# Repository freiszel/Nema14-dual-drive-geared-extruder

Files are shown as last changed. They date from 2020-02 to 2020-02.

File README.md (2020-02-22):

# Nema14-dual-drive-geared-extruder
A Nema 14 dual drive geared extruder made from scratch. The prject was made with SolidWoks 2010 
(any posterior version of SolidWorks will open the files). The SolidWors2010 folder contains all the parts required,
as weel as the assembly file "Gear 15x69.SLDASM". 15x69 stands for the gears' teeth number used in the project.  

The project was used to extrude a 1.75 mm ABS filament heated to 220C through a 0,4 mm nozzle. A Feed Rate of 9 mm/s
was possible without slipping or motor stall. ths means that flow rate obtained was 25 mm3/s, enough to print at 
speeds of 200 mm/s.

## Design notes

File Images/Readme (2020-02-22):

Images show the mounting sequence of all parts of the Nema14 Dual Drive Geared Extruder.

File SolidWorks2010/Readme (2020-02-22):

Solidworks2010 files of all parts of the Nema14 Dual Drive Geared Extruder.
The Assembly file is  "Gear 15x69.SLDASM".
15x69 stands for the gears' teeth number.

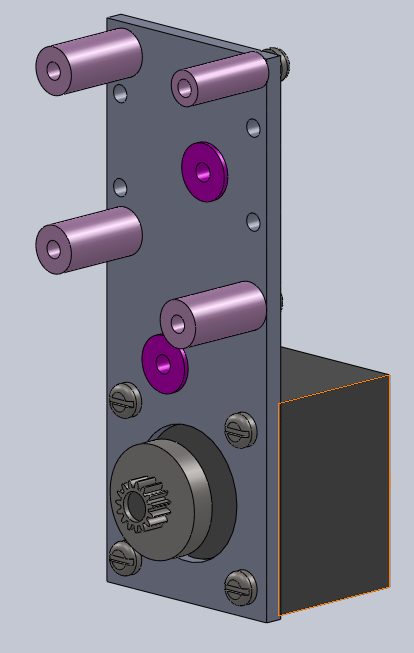
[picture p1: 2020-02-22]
Images/02_BackPlateMounted.png

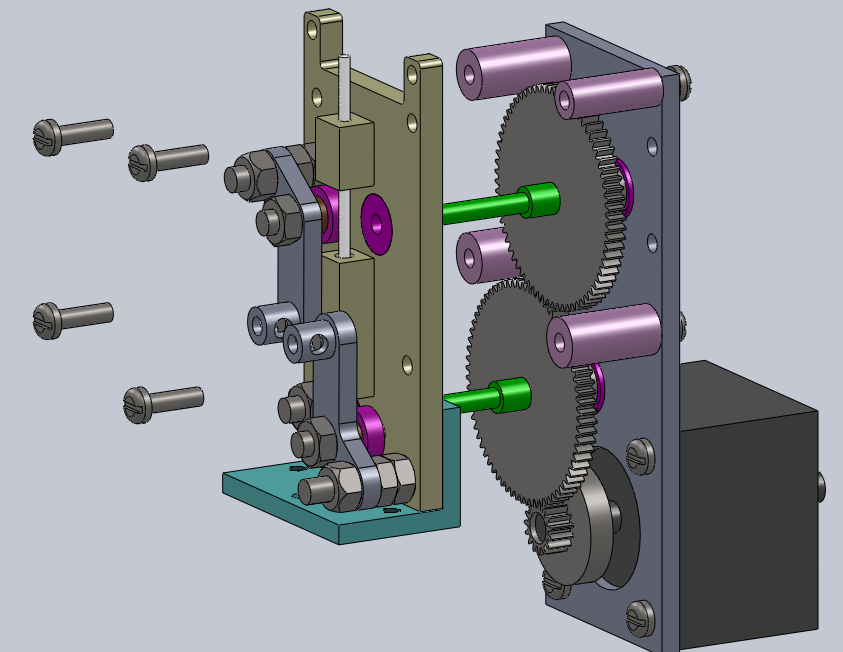
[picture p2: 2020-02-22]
Images/10_FrontToRealMounting.png

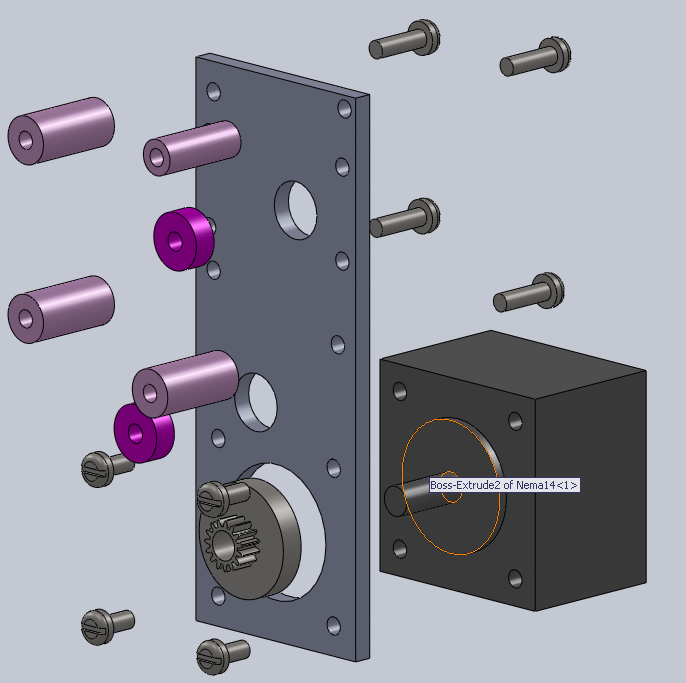
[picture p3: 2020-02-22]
Images/01_BackPlateMounting.png

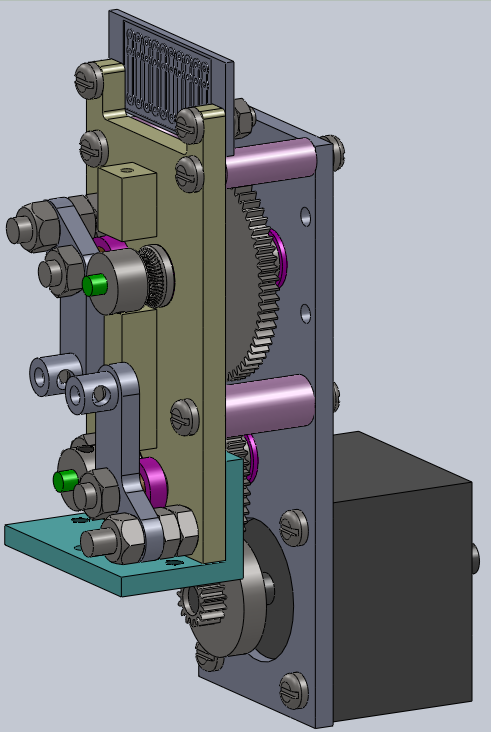
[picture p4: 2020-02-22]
Images/13_DriversAndConectorFixed.png

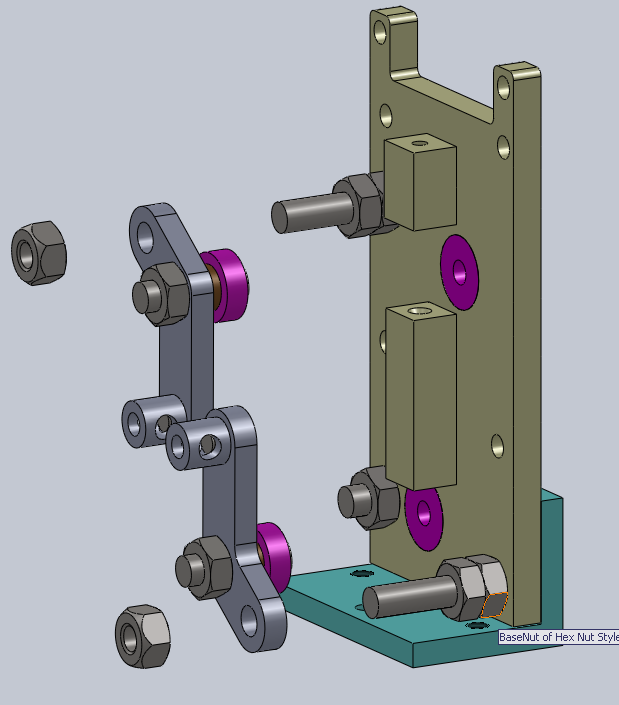
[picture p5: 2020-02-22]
Images/08_AttachPressingArms.png

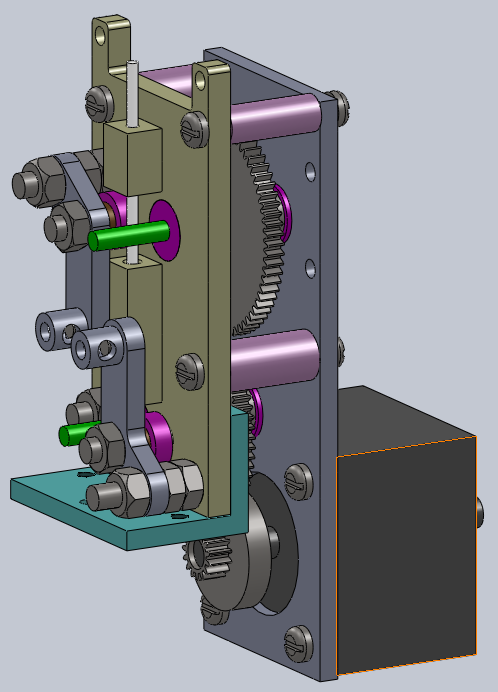
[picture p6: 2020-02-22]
Images/11_FrontToRearMounted.png

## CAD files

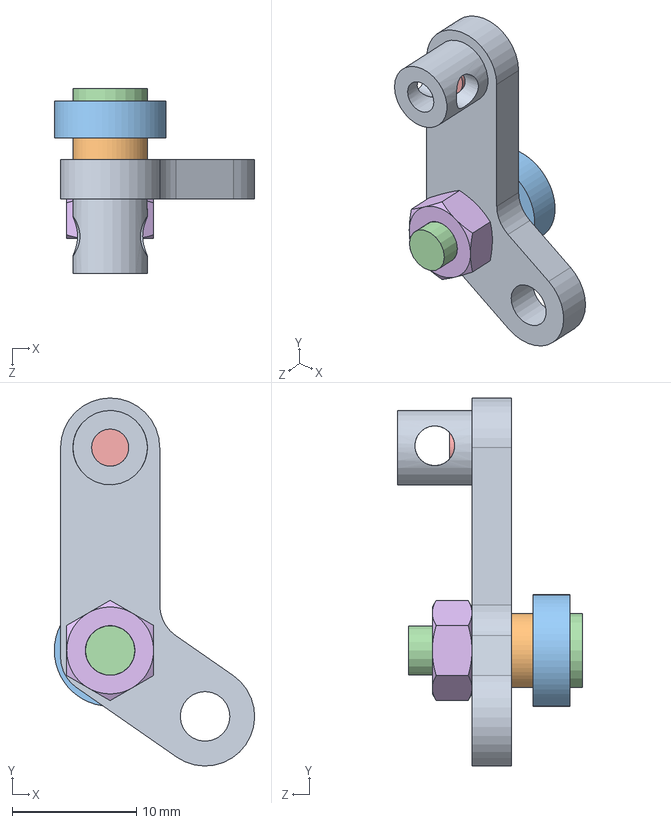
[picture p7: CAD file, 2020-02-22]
SolidWorks2010/PressingArm.SLDASM
16.1 x 29.7 x 14.9 mm
alavanca
BrassBush
bear 9 x 5 x 3mm
FlatScrew
Flat Head Screw_AM
Hex Nut Style 1_AM

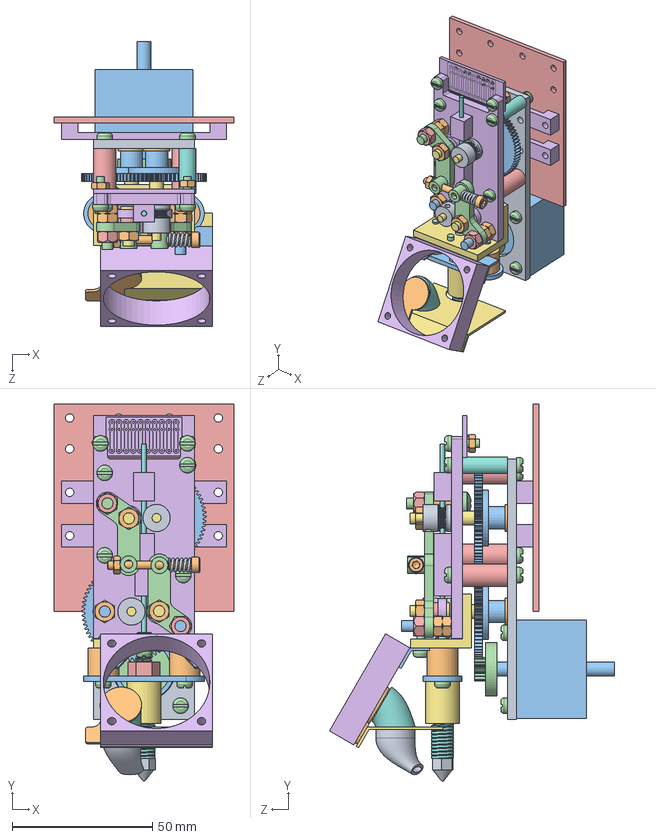
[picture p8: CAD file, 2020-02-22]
SolidWorks2010/Gear 15x69.SLDASM
64.0 x 134.4 x 101.7 mm
rear
bear 3 16 x x1 8 x 4mm x 4
Nema14
GearN15M05
fixacaoX
front
aba
filamento
trator x 2
Hex Nut Style 1_AM x 10
Flat Head Screw_AM x 4
Pan Cross Head_AM
Prevailing Torque Hex Nut_am x 2
Ponte x 2
Peek
heater
nozzle
PeekPilar x 2
fibra
Teflon
PeekNut
fan
coifa1
coifa2
coifa3
bloqueador
CollerFix
Pan Slot Head_AM x 17
Pilar x 3
conector
Pino x 2
Pilar 6mm
spring
Socket Head Cap Screw_AM
GearN69M05 x 2
alavanca x 2
BrassBush x 2
bear 9 x 5 x 3mm x 2
FlatScrew x 2

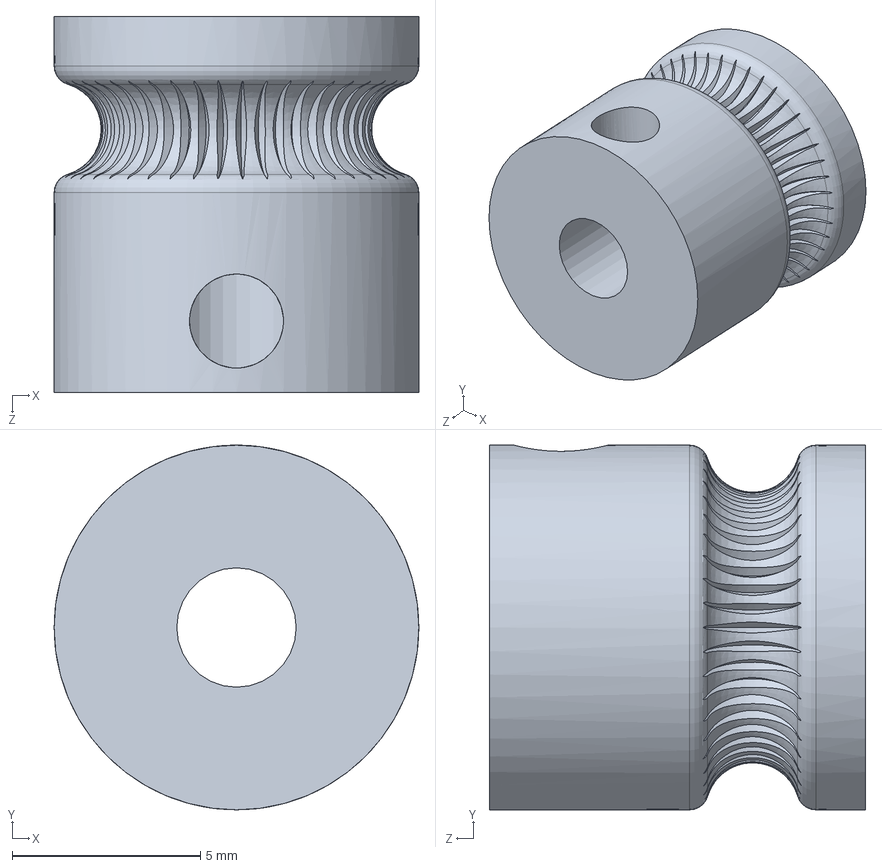
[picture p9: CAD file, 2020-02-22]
SolidWorks2010/trator.SLDPRT
9.70 x 9.70 x 10.0 mm

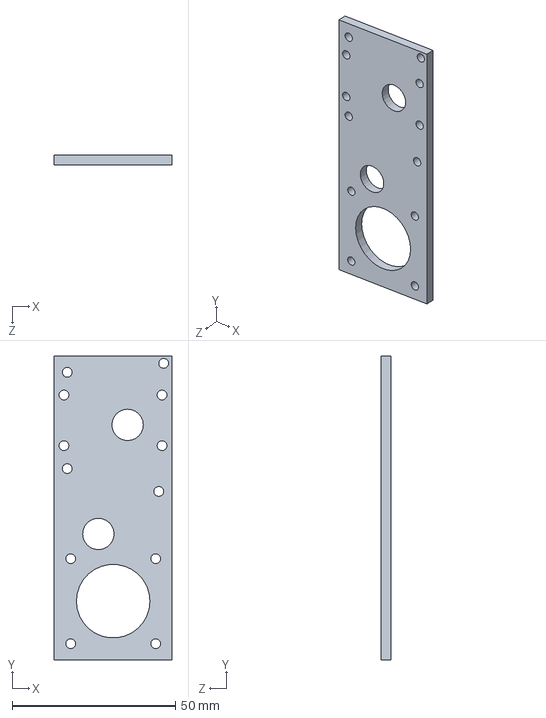
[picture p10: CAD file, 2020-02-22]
SolidWorks2010/rear.SLDPRT
36.0 x 93.0 x 3.17 mm

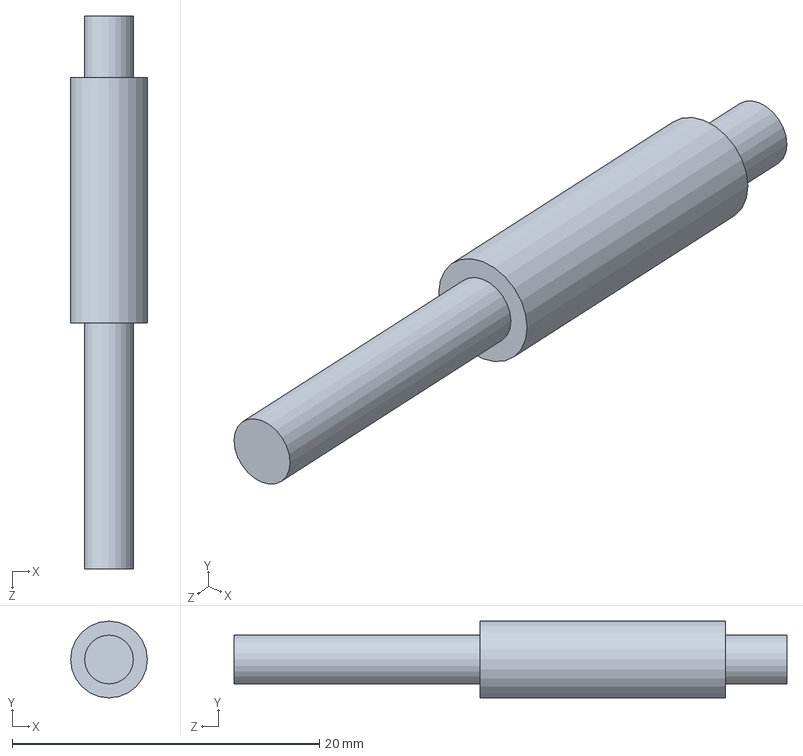
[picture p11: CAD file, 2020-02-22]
SolidWorks2010/Pino.SLDPRT
5.00 x 5.00 x 36.0 mm

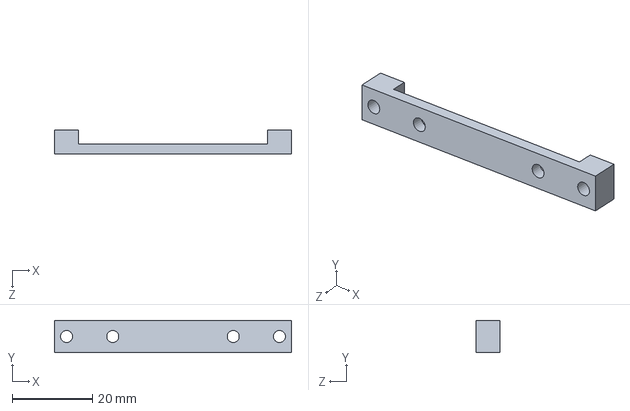
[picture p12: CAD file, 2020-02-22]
SolidWorks2010/Ponte.SLDPRT
59.0 x 8.00 x 6.00 mm

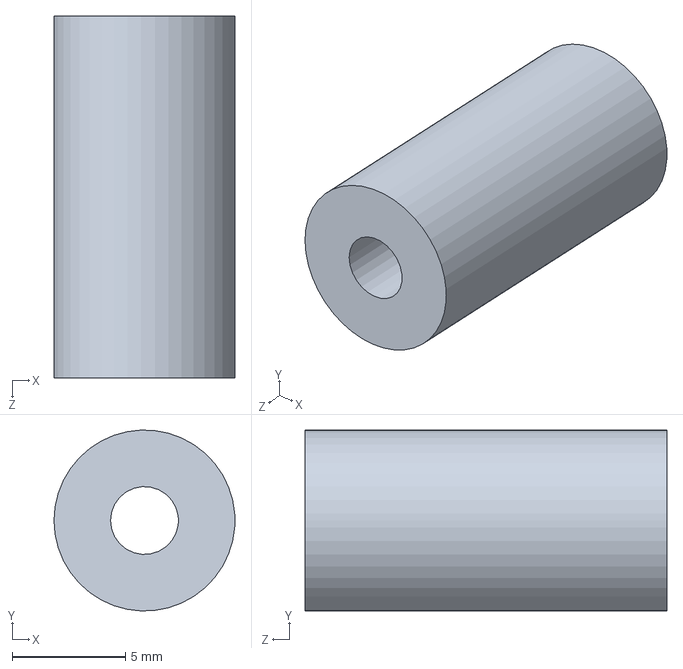
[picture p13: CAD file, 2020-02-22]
SolidWorks2010/Pilar.SLDPRT
8.00 x 7.99 x 16.0 mm

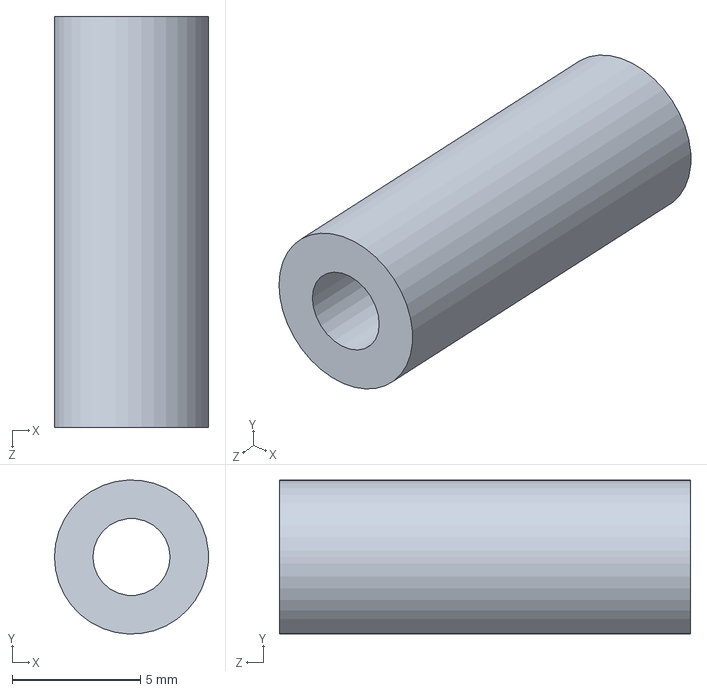
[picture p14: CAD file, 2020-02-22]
SolidWorks2010/Pilar 6mm.SLDPRT
6.00 x 5.99 x 16.0 mm

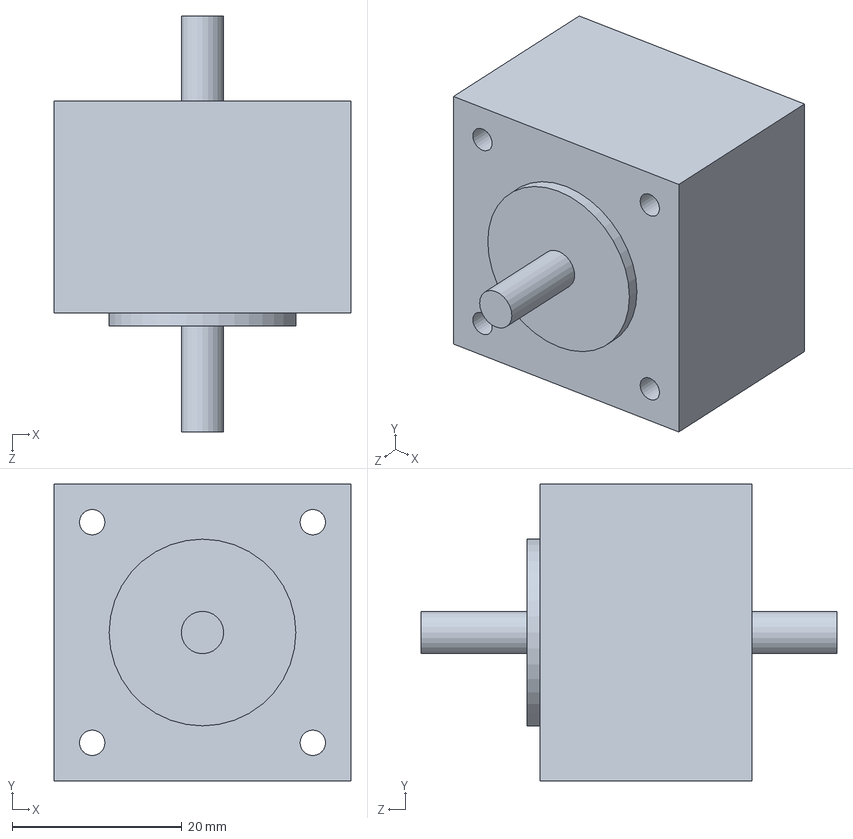
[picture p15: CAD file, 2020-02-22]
SolidWorks2010/Nema14.SLDPRT
35.0 x 35.0 x 49.0 mm

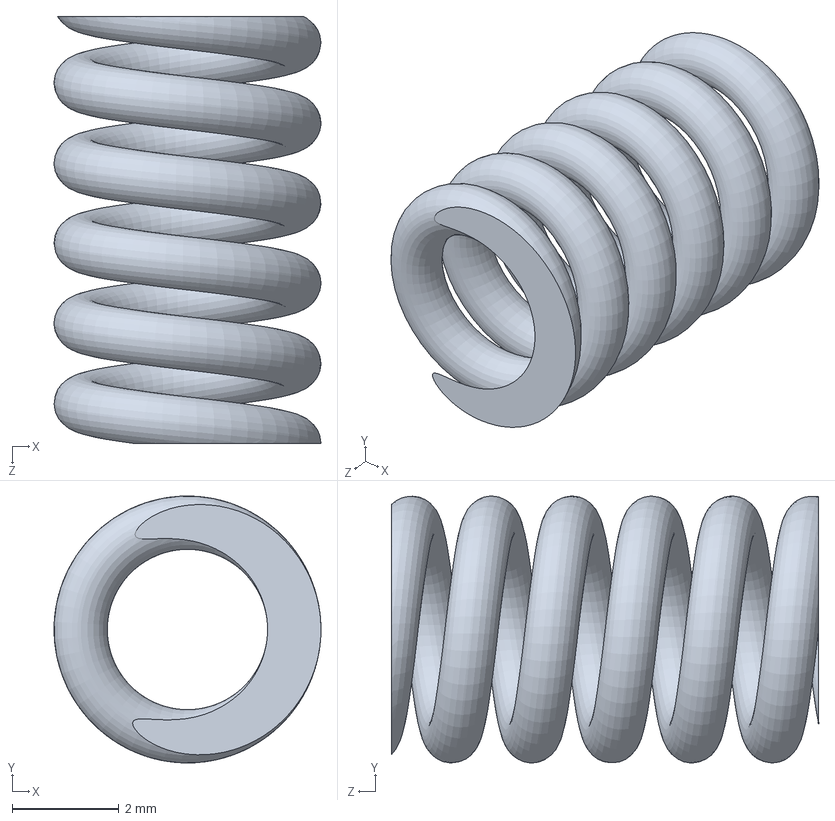
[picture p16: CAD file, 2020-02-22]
SolidWorks2010/spring.SLDPRT
5.00 x 5.00 x 8.00 mm

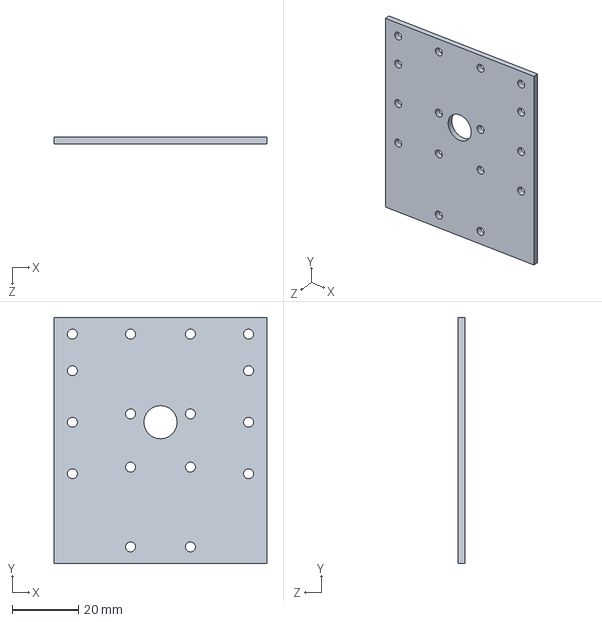
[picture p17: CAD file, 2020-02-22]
SolidWorks2010/fixacaoX.SLDPRT
64.0 x 74.0 x 2.00 mm

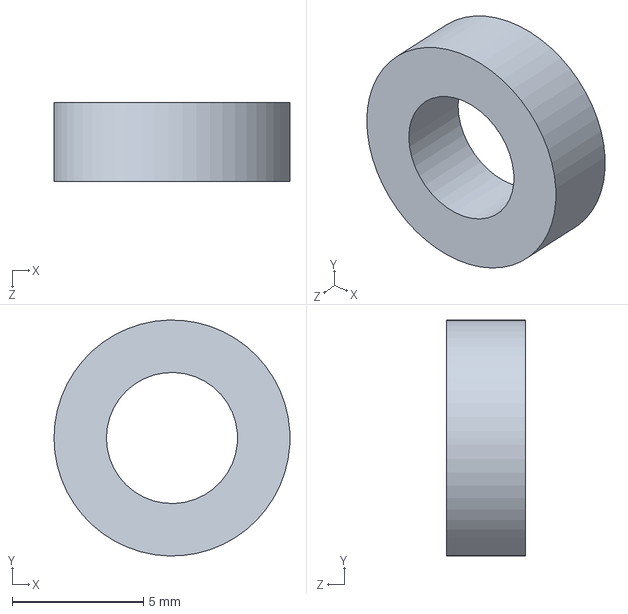
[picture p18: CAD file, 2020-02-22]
SolidWorks2010/bear 9 x 5 x 3mm.SLDPRT
9.00 x 9.00 x 3.00 mm

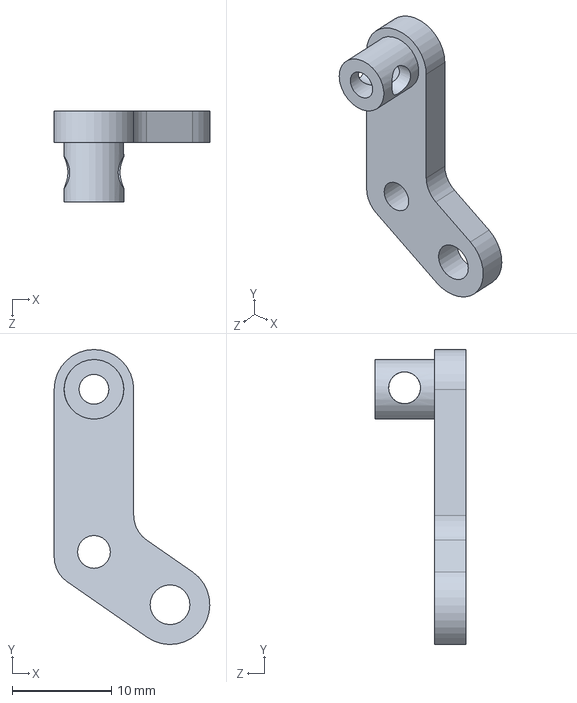
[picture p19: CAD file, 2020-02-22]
SolidWorks2010/alavanca.SLDPRT
15.6 x 29.7 x 9.20 mm

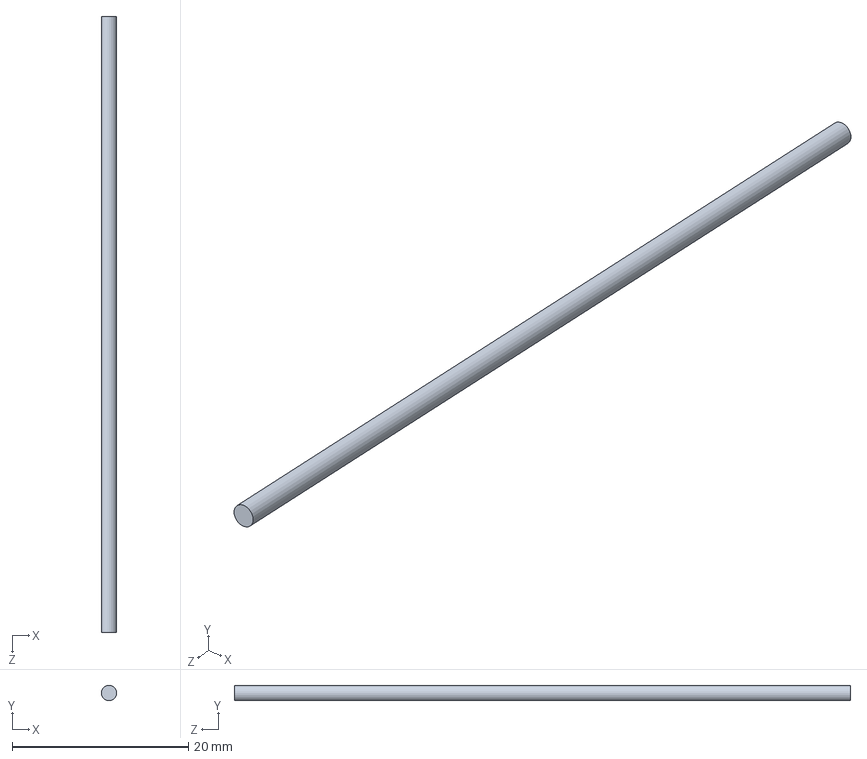
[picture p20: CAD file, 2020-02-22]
SolidWorks2010/filamento.SLDPRT
1.75 x 1.75 x 70.0 mm

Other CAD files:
SolidWorks2010/geometria.SLDPRT
SolidWorks2010/front.SLDPRT
SolidWorks2010/GearN69M05.sldprt
SolidWorks2010/aba.SLDPRT
SolidWorks2010/BrassBush.SLDPRT
SolidWorks2010/FlatScrew.SLDPRT
SolidWorks2010/GearN15M05.sldprt
SolidWorks2010/bear 3 16 x x1 8 x 4mm.SLDPRT
SolidWorks2010/conector.SLDPRT

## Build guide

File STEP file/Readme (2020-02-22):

STEP file with all parts of the Nema14 Dual Drive Geared Extruder

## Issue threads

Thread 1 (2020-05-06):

Weight

RedAnon, 2020-05-06:
Hi,
how much does the whole contraption weights without a stepper motor?

freiszel, 2020-05-06:
Hi:

Without motor: 135 g. With motor: 245 g

..

Em qua., 6 de mai. de 2020 às 15:33, Ladislav Ezr jr. <
notifications@github.com> escreveu:

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

RedAnon, 2020-05-06:
That's hella light. Have you ever thought about a direct drive version? That would be real sweet for a delta.

freiszel, 2020-05-06:
Yes, indeed, a direct drive is lighter. I devised the dual drive just to
investigate the increase in extruding force.

..

Em quarta-feira, 6 de maio de 2020, Ladislav Ezr jr. <
notifications@github.com> escreveu:

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

RedAnon, 2020-05-07:
Sorry, that's not what I've meant. I was talking about your design but instead of the stepper motor being mounted on the extruder there would be a drive cable. You could also use lighter material (carbon fiber instead of aluminum) to further lower the weight.
That would be the best possible design for a delta printer IMHO.

RedAnon, 2020-05-07:
Also do you have the specs on the stepper motor you have used? What was the holding torque?

freiszel, 2020-05-07:
The motor was taken from an old table scanner. In the photo you can see a
tag with few specs: current per phase 0.5 A and phase resistance 3.8 ohms.
No clue about holding torque. The motor is made by Applied Motion, model
5014-819. I have looked on the internet for more detailed specs without
success. It seens to be a very old model.
..

Em qui., 7 de mai. de 2020 às 13:37, Ladislav Ezr jr. <
notifications@github.com> escreveu:

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

RedAnon, 2020-05-07:
Ah, that's too bad. Anyway I will try to replicate it over the weekend. Looking at the stepper motors the Sanyo Denki SS2421-5041/SS2422-5041 (0.083N⋅m/0.186N⋅m and 70g/140g) models look real nice. Light and compact. But they are NEMA 17. There doesn't seem to be much choice in the NEMA 14/NEMA 11 (and smaller) sizes when weight is an issue.

How about the gearing? Would you stay with the 4.6:1 gear ratio? Or go higher? 5:1?

freiszel, 2020-05-07:
I had plastic gears in my scrap box that yelded this 4.6:1  gear ratio.
That was the only reason I choose this ratio.  A 5:1 ratio would word as
well.

...

Em quinta-feira, 7 de maio de 2020, Ladislav Ezr jr. <
notifications@github.com> escreveu:

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

RedAnon, 2020-05-08:
Nice. BTW what kind of nozzle did you use?

freiszel, 2020-05-08:
A standart 0.4 mm nozzle, M6 screw.

Em sexta-feira, 8 de maio de 2020, Ladislav Ezr jr. <
notifications@github.com> escreveu:

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

RedAnon, 2020-05-08:
You reckon it would be faster with a Vulcano extruder from E3D?

freiszel, 2020-05-08:
By "faster" you mean to assembly a complete extruder as soon as possible,
without having the burden of doing everything ? Of course it is!

But if you mean that with a Volcano hotend you can print faster, I doubt if
there is any advantage over others hot ends.

Em sex., 8 de mai. de 2020 às 13:24, Ladislav Ezr jr. <
notifications@github.com> escreveu:

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

RedAnon, 2020-05-08:
I meant print speed. Because in theory the more powerful the heater cartridge is the faster you can print. I have no idea how can longer nozzle effect the speed but apparently it does? Even tho the advertised 30mm3/s seems really high and almost everyone peaks at 20. I kinda don't believe the E3D numbers...

freiszel, 2020-05-08:
For a 1.75mm filament, 30mm3/s means a flow rate of 12.5 mm/s.  The
extruder I devised can reach a flow rate of almost 10 mm/s, not so far from
12.5mm/s.

So, it is plausible that an extruder can reach 12.5 mm/s. But this depends
on the force to push the filament to the hot end. This force does not
depends on the hot end, but only on the motor/gear ratio.
...

Em sexta-feira, 8 de maio de 2020, Ladislav Ezr jr. <
notifications@github.com> escreveu:

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
